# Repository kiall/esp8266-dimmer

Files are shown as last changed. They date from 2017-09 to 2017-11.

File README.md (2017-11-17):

ESP8266 Light Dimmer
====================

KiCad Schematic and PCB Design for a ESP8266 / ESP-03 based light dimmer.

Tested as working - see revision history for more.

## Board Images

Front:

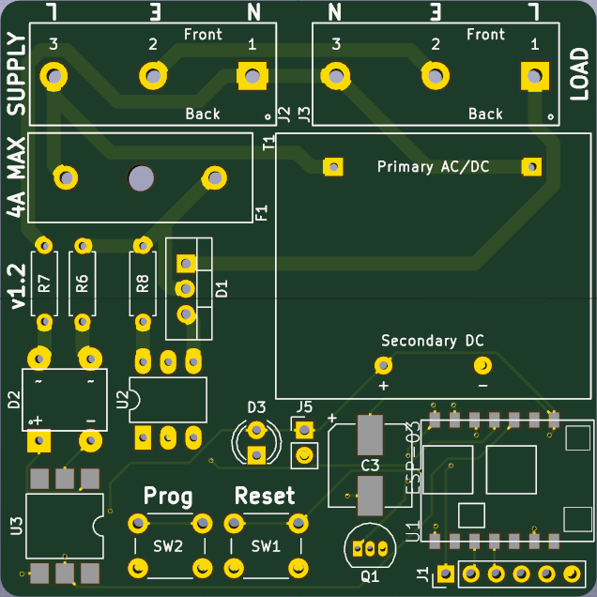
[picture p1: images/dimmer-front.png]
Front


Back:

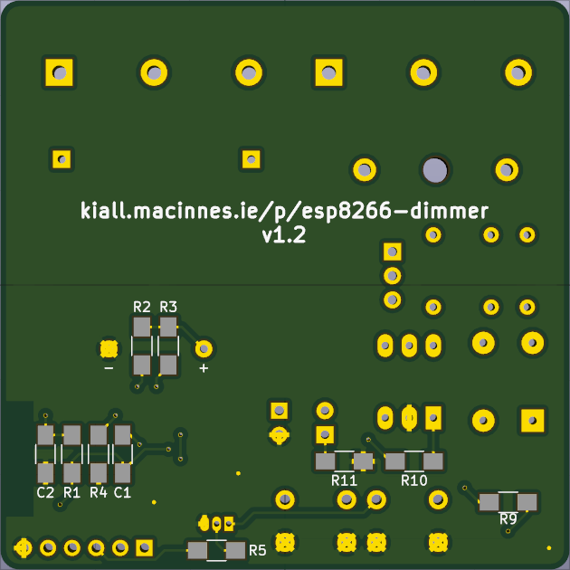
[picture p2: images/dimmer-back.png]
Back


## Revision History:

### v1.2:

v1.2 is tested as working.

Fixes:

* Fix PSU Ordering - Secondary DC + and - pins swapped.
* U3 pad size corrected
* C3 470uF footprint corrected
* Add 3v3 + GND power inputs for programming without a mains connection
* PCB Layout reworked

Issues Not Yet Fixed:

* More space behind D1 (Triac) would be better, to allow for a larger heatsink.
* 3v3 + GND power inputs for programming without a mains connection should be labeled on the board.
### v1.1:

Fixes:

* Fix Traic Pin Ordering

Issues Not Yet Fixed:

* None

## References

* [Dimming Circuit](https://www.instructables.com/id/Arduino-controlled-light-dimmer-The-circuit/)
* [BoM Generator](https://github.com/SchrodingersGat/KiBoM)

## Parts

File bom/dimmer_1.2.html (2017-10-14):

Source File | /home/kiall/kicad/projects/esp8266-dimmer/kicad/dimmer.sch
BoM Date | Sat 14 Oct 2017 14:27:11 IST
Schematic Version | 1.2
Schematic Date
KiCad Version | Eeschema 4.0.7
Component Groups | 23
Component Count (per PCB) | 29
Fitted Components (per PCB) | 29
Number of PCBs | 1
Total Component Count (for 1 PCBs) | 29
 | Description | Part | References | Value | Footprint | Quantity Per PCB | Datasheet
1 | Unpolarized capacitor | C | C1 | 0.1uF | C_1206_HandSoldering | 1
2 | Polarised capacitor | CP | C2 | 0.1uF | C_1206_HandSoldering | 1
3 | Polarised capacitor | CP | C3 | 470uF | CP_Elec_8x10.5 | 1
4 | triode for alternating current (TRIAC) | Q_TRIAC_AAG | D1 | BT136X-600 | TO-220-3_Vertical | 1
5 | Diode bridge (pins: 1=+, 2=-, 3=AC, 4=AC) | DF04M-E3/45 | D2 | DF04M-E3/45 | DF-M | 1
6 | LED generic | LED | D3 | LED | LED_D4.0mm | 1
7 | Fuse, generic | Fuse | F1 | 5A | Fuse_Holder_5x20mm_P15mm | 1
8 | Generic screw terminal, single row, 01x03 | Screw_Terminal_01x03 | J2 | AC IN | RS_Pro_10mm_Pitch_3_Way_PCB_Terminal_Block | 1
9 | Generic connector, single row, 01x06 | Conn_01x06_Female | J1 | FTDI | Socket_Strip_Straight_1x06_Pitch2.54mm | 1
10 | Generic connector, single row, 01x03 | Conn_01x03 | J3 | Load Out | RS_Pro_10mm_Pitch_3_Way_PCB_Terminal_Block | 1
11 | Generic connector, single row, 01x02 | Conn_01x02 | J5 | PWRIN | Pin_Header_Straight_1x02_Pitch2.54mm | 1
12 | Transistor PNP (general) | Q_PNP_EBC | Q1 | S8550 PNP | TO-92_Inline_Narrow_Oval | 1
13 | Resistor | R | R1 R2 R3 R4 R5 R9 | 10k | R_1206_HandSoldering | 6
14 | Resistor | R | R8 | 1k | R_Axial_DIN0207_L6.3mm_D2.5mm_P7.62mm_Horizontal | 1
15 | Resistor | R | R10 | 220 | R_1206_HandSoldering | 1
16 | Resistor | R | R6 R7 | 30k | R_Axial_DIN0207_L6.3mm_D2.5mm_P7.62mm_Horizontal | 2
17 | Resistor | R | R11 | 330 | R_1206_HandSoldering | 1
18 | Single Pole Single Throw (SPST) switch | SW_SPST | SW2 | Prog | SW_PUSH_6mm | 1
19 | Single Pole Single Throw (SPST) switch | SW_SPST | SW1 | Reset | SW_PUSH_6mm | 1
20 | Transformer, single primary, single output, regulated | Transformer_Myrra_47000_1P_1S | T1 | Myrra_47121 | Transformer_Myrra_47000_1P_1S | 1
21 | DC Optocoupler Base Connected, Vce 30V, CTR 20%, Viso 2500V, DIP6 | 4N25 | U3 | 4N25 | SMDIP-6_W9.53mm | 1 | https://www.vishay.com/docs/83725/4n25.pdf
22 | ESP8266 ESP-03 module, 14 pins, 2mm, ceramic antenna | ESP-03 | U1 | ESP-03 | ESP-03 | 1 | http://l0l.org.uk/2014/12/esp8266-modules-hardware-guide-gotta-catch-em-all/
23 | Random Phase Opto-Triac, Vdrm 250V, Ift 15mA, DIP6 | MOC3021M | U2 | MOC3021M | DIP-6_W7.62mm_LongPads | 1 | http://www.fairchildsemi.com/ds/MO/MOC3020M.pdf

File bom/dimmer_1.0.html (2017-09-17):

Source File | /home/kiall/KiCad Projects/dimmer/kicad/dimmer.sch
BoM Date | Sun 17 Sep 2017 14:10:56 IST
Schematic Version | 1.0
Schematic Date
KiCad Version | Eeschema 4.0.7
Component Groups | 22
Component Count (per PCB) | 28
Fitted Components (per PCB) | 28
Number of PCBs | 1
Total Component Count (for 1 PCBs) | 28
 | Description | Part | References | Value | Footprint | Quantity Per PCB | Datasheet
1 | Unpolarized capacitor | C | C1 | 0.1uF | C_1206_HandSoldering | 1
2 | Polarised capacitor | CP | C2 | 0.1uF | C_1206_HandSoldering | 1
3 | Polarised capacitor | CP | C3 | 470uF | C_1206_HandSoldering | 1
4 | triode for alternating current (TRIAC) | Q_TRIAC_AAG | D1 | BT136X-600 | TO-220_Vertical | 1
5 | Diode bridge (pins: 1=+, 2=-, 3=AC, 4=AC) | DF04M-E3/45 | D2 | DF04M-E3/45 | DF-M | 1
6 | LED generic | LED | D3 | LED | LED_D4.0mm | 1
7 | Fuse, generic | Fuse | F1 | 5A | Fuse_Holder_5x20mm_P15mm | 1
8 | Generic screw terminal, single row, 01x03 | Screw_Terminal_01x03 | J2 | AC IN | RS_Pro_10mm_Pitch_3_Way_PCB_Terminal_Block | 1
9 | Generic connector, single row, 01x06 | Conn_01x06_Female | J1 | FTDI | Socket_Strip_Straight_1x06_Pitch2.54mm | 1
10 | 2-pin jumper/solder bridge | GS2 | J4 | LED_BYPASS | GS2 | 1
11 | Generic connector, single row, 01x03 | Conn_01x03 | J3 | Load Out | RS_Pro_10mm_Pitch_3_Way_PCB_Terminal_Block | 1
12 | Transistor PNP (general) | Q_PNP_EBC | Q1 | S8550 PNP | TO-92_Inline_Narrow_Oval | 1
13 | Resistor | R | R1 R2 R3 R4 R5 R9 | 10k | R_1206_HandSoldering | 6
14 | Resistor | R | R8 | 1k | R_Axial_DIN0207_L6.3mm_D2.5mm_P7.62mm_Horizontal | 1
15 | Resistor | R | R10 | 220 | R_1206_HandSoldering | 1
16 | Resistor | R | R6 R7 | 30k | R_Axial_DIN0207_L6.3mm_D2.5mm_P7.62mm_Horizontal | 2
17 | Single Pole Single Throw (SPST) switch | SW_SPST | SW2 | Prog | SW_PUSH_6mm | 1
18 | Single Pole Single Throw (SPST) switch | SW_SPST | SW1 | Reset | SW_PUSH_6mm | 1
19 | Transformer, single primary, single output, regulated | Transformer_Myrra_47000_1P_1S | T1 | Myrra_47121 | Transformer_Myrra_47000_1P_1S | 1
20 | DC Optocoupler Base Connected, Vce 30V, CTR 20%, Viso 2500V, DIP6 | 4N25 | U3 | 4N25 | DIP-6_W7.62mm_SMD | 1 | https://www.vishay.com/docs/83725/4n25.pdf
21 | ESP8266 ESP-03 module, 14 pins, 2mm, ceramic antenna | ESP-03 | U1 | ESP-03 | ESP-03 | 1 | http://l0l.org.uk/2014/12/esp8266-modules-hardware-guide-gotta-catch-em-all/
22 | Random Phase Opto-Triac, Vdrm 250V, Ift 15mA, DIP6 | MOC3021M | U2 | MOC3021M | DIP-6_W7.62mm_LongPads | 1 | http://www.fairchildsemi.com/ds/MO/MOC3020M.pdf

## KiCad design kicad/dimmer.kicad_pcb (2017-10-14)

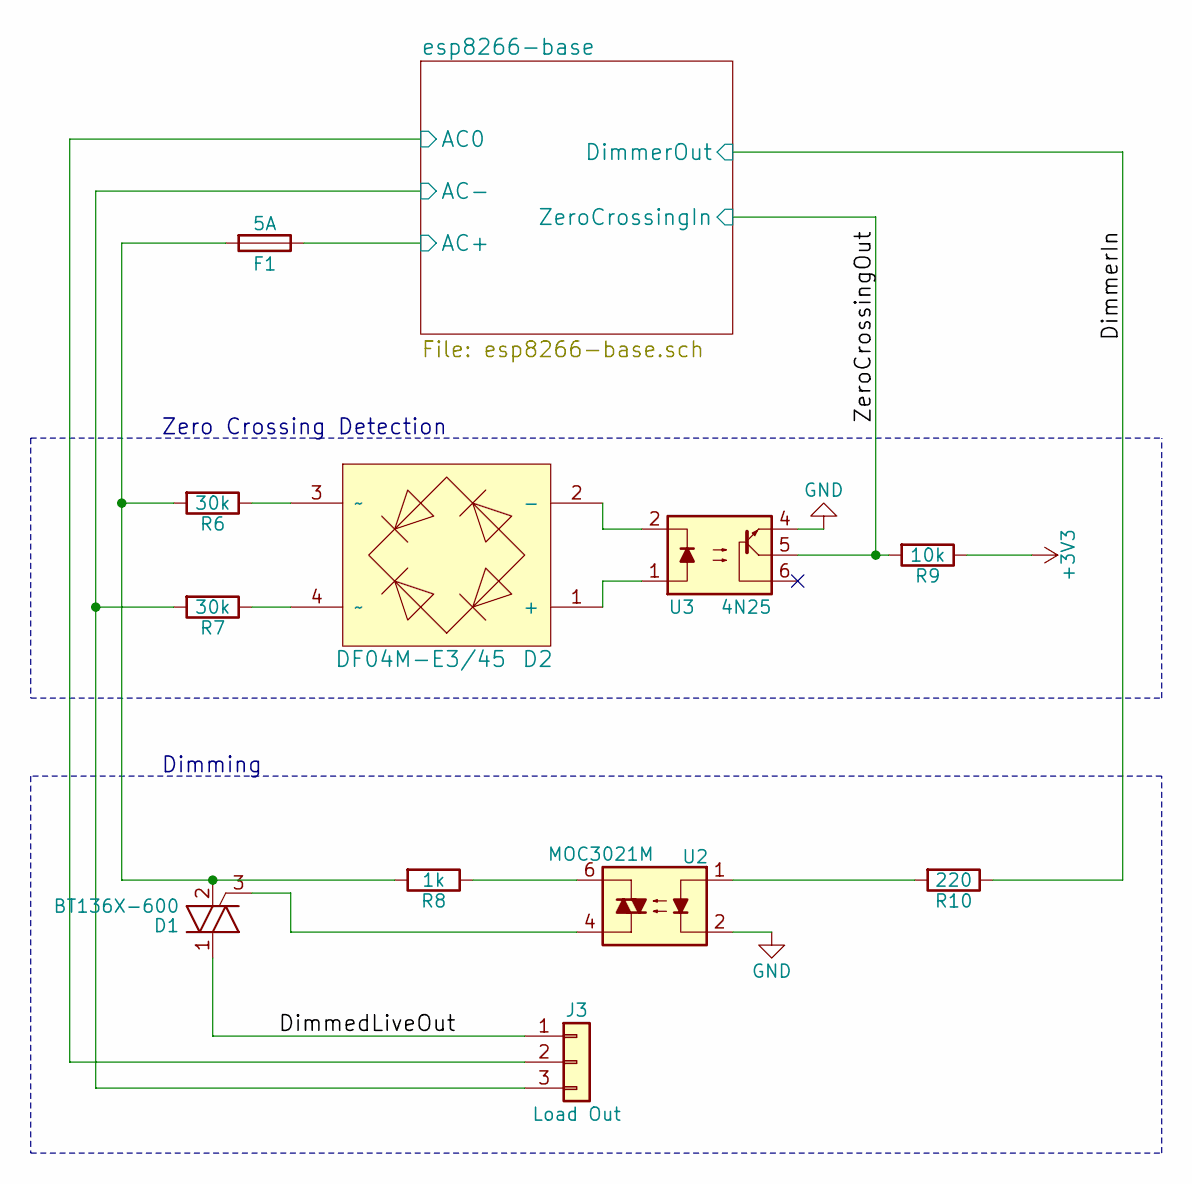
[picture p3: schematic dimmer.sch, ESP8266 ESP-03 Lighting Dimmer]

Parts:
D1: BT136X-600; TO-220-3_Vertical
D2: DF04M-E3/45; DF-M
F1: 5A; Fuse_Holder_5x20mm_P15mm
J3: Load Out; RS_Pro_10mm_Pitch_3_Way_PCB_Terminal_Block
R6, R7: 30k; R_Axial_DIN0207_L6.3mm_D2.5mm_P7.62mm_Horizontal
R8: 1k; R_Axial_DIN0207_L6.3mm_D2.5mm_P7.62mm_Horizontal
R9: 10k; R_1206_HandSoldering
R10: 220; R_1206_HandSoldering
U2: MOC3021M; DIP-6_W7.62mm_LongPads
U3: 4N25; SMDIP-6_W9.53mm

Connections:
+3V3: R9.1; also elsewhere on the board
/DimmedLiveOut: D1.1 (A1), J3.1
/DimmerIn: R10.1; also elsewhere on the board
/ZeroCrossingOut: R9.2, U3.5; also elsewhere on the board
/esp8266-base/AC0: J3.2; also elsewhere on the board
/esp8266-base/AC+: F1.1; also elsewhere on the board
/esp8266-base/AC-: J3.3, R7.2; also elsewhere on the board
GND: U2.2, U3.4; also elsewhere on the board
unnamed: D1.2 (A2), F1.2, R6.2, R8.2
unnamed: D1.3 (G), U2.4
unnamed: D2.1 (+), U3.1
unnamed: D2.2 (-), U3.2
unnamed: D2.3 (~~), R6.1
unnamed: D2.4 (~~), R7.1
unnamed: R8.1, U2.6
unnamed: R10.2, U2.1

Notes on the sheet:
Zero Crossing Detection
Dimming

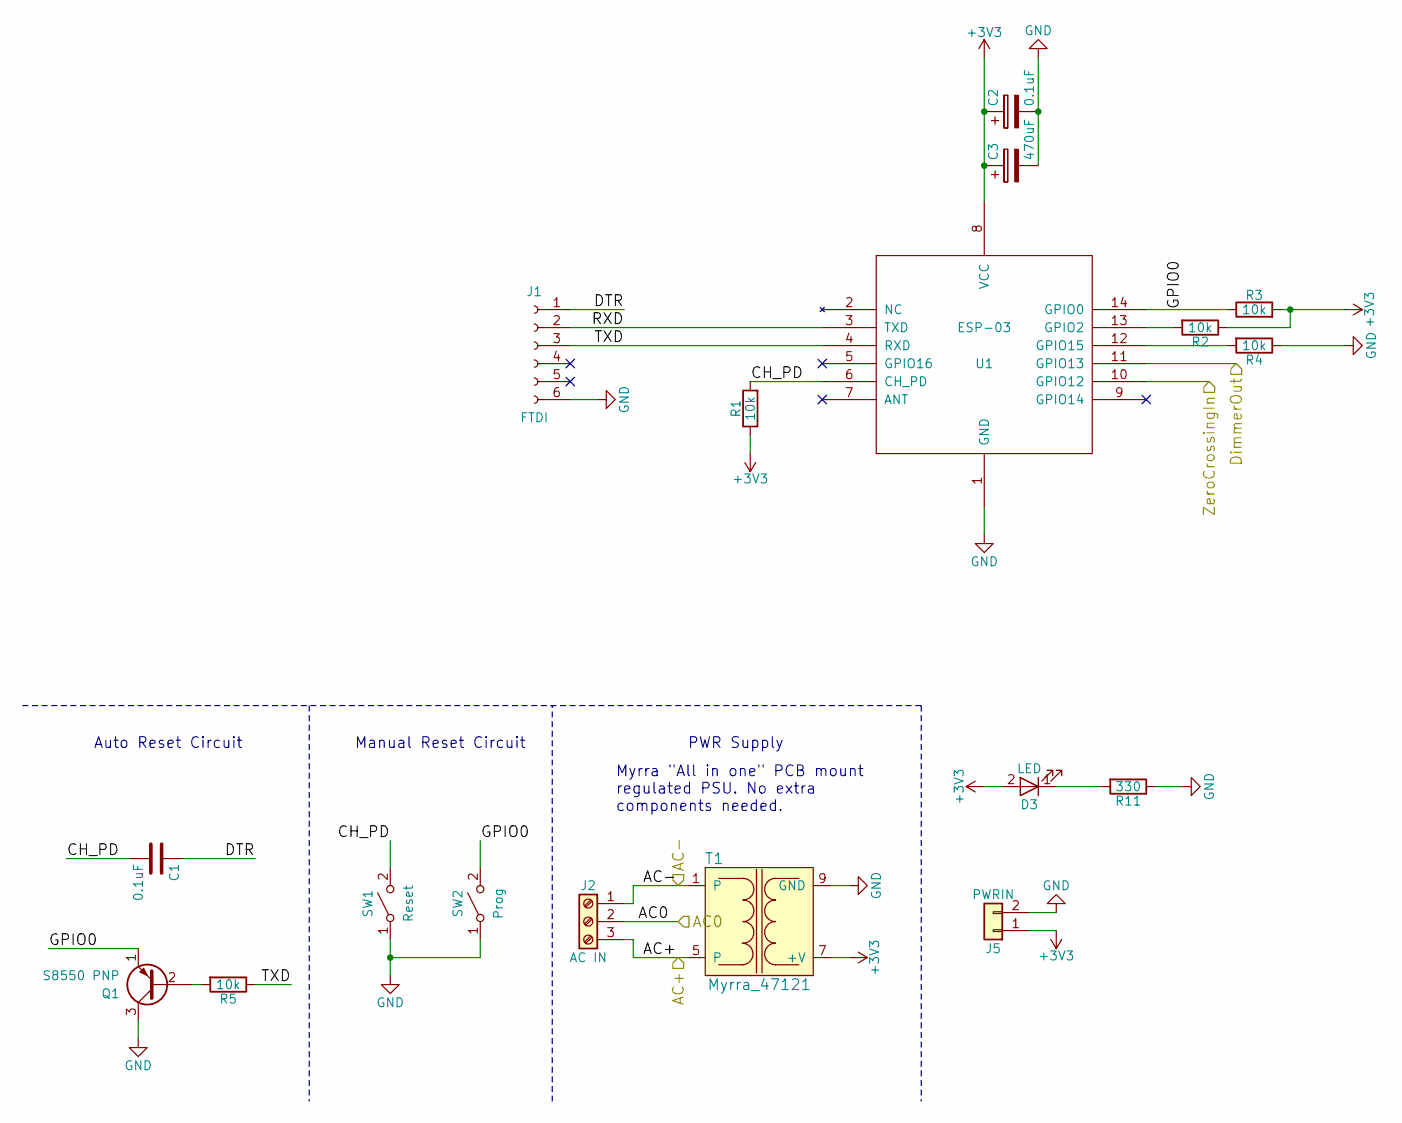
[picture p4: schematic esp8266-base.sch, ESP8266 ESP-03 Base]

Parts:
C1, C2: 0.1uF; C_1206_HandSoldering
C3: 470uF; CP_Elec_8x10.5
D3: LED; LED_D4.0mm
J1: FTDI; Socket_Strip_Straight_1x06_Pitch2.54mm
J2: AC IN; RS_Pro_10mm_Pitch_3_Way_PCB_Terminal_Block
J5: PWRIN; Pin_Header_Straight_1x02_Pitch2.54mm
Q1: S8550 PNP; TO-92_Inline_Narrow_Oval
R1, R2, R3, R4, R5: 10k; R_1206_HandSoldering
R11: 330; R_1206_HandSoldering
SW1: Reset; SW_PUSH_6mm
SW2: Prog; SW_PUSH_6mm
T1: Myrra_47121; Transformer_Myrra_47000_1P_1S
U1: ESP-03

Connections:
+3V3: C2.1, C3.1, D3.2 (A), J5.1, R1.1, R2.1, R3.2, T1.7 (+V), U1.8 (VCC); also elsewhere on the board
/DimmerIn: U1.11 (GPIO13); also elsewhere on the board
/ZeroCrossingOut: U1.10 (GPIO12); also elsewhere on the board
/esp8266-base/AC0: J2.2; also elsewhere on the board
/esp8266-base/AC+: J2.3, T1.5; also elsewhere on the board
/esp8266-base/AC-: J2.1, T1.1; also elsewhere on the board
/esp8266-base/CH_PD: C1.2, R1.2, SW1.2 (B), U1.6 (CH_PD)
/esp8266-base/DTR: C1.1, J1.1
/esp8266-base/GPIO0: Q1.1 (E), R3.1, SW2.2 (B), U1.14 (GPIO0)
/esp8266-base/RXD: J1.2, U1.3 (TXD)
/esp8266-base/TXD: J1.3, R5.1, U1.4 (RXD)
GND: C2.2, C3.2, J1.6, J5.2, Q1.3 (C), R4.1, R11.1, SW1.1 (A), SW2.1 (A), T1.9 (GND), U1.1 (GND); also elsewhere on the board
unnamed: D3.1 (K), R11.2
unnamed: Q1.2 (B), R5.2
unnamed: R2.2, U1.13 (GPIO2)
unnamed: R4.2, U1.12 (GPIO15)

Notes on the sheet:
Auto Reset Circuit
Manual Reset Circuit
PWR Supply
Myrra "All in one" PCB mount regulated PSU. No extra components needed.

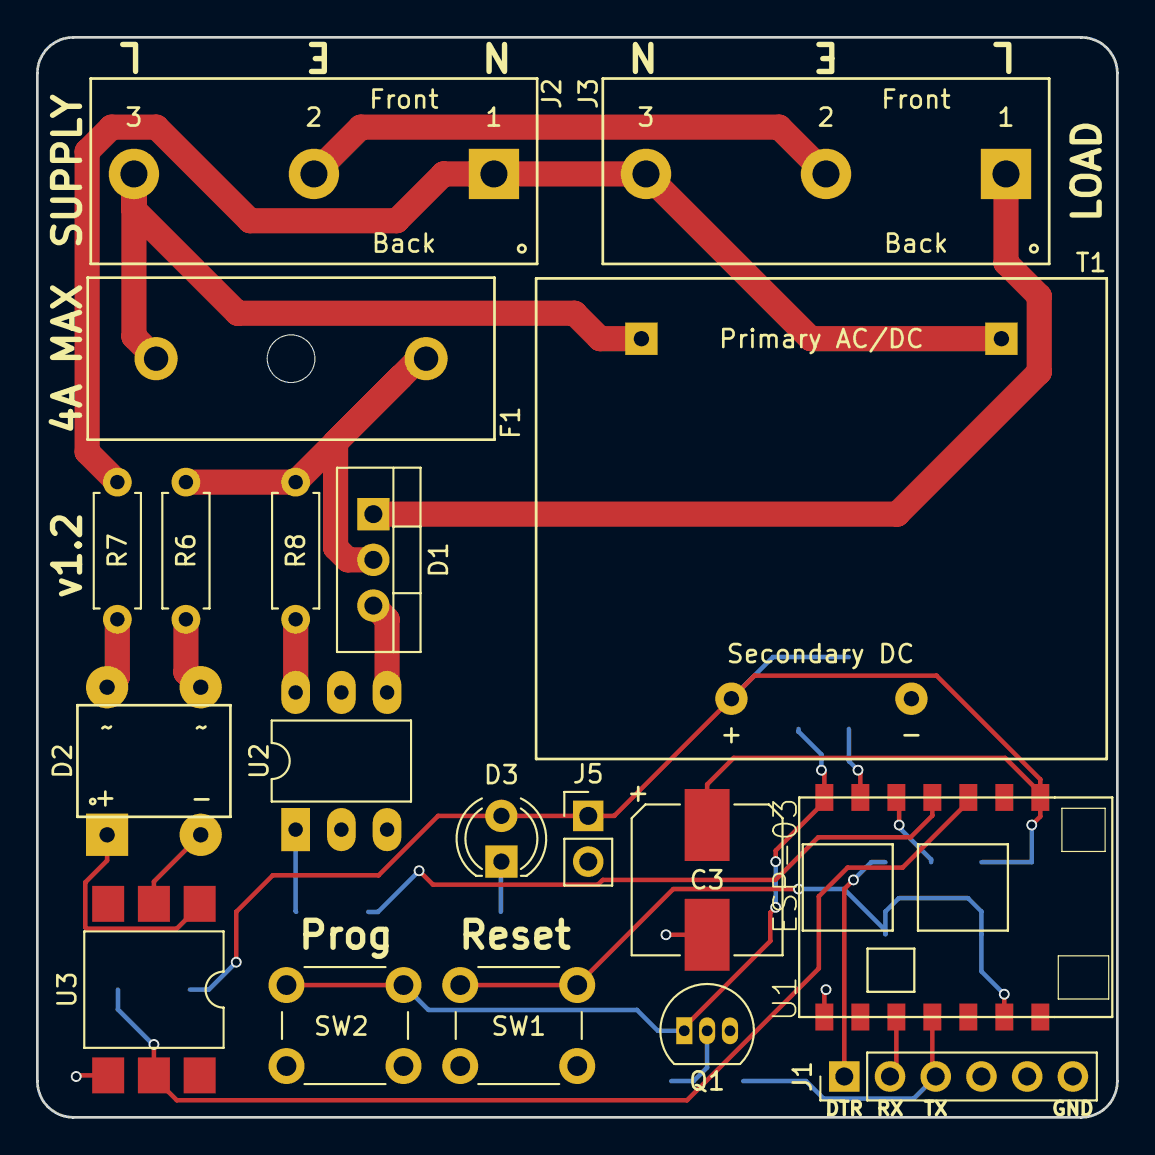
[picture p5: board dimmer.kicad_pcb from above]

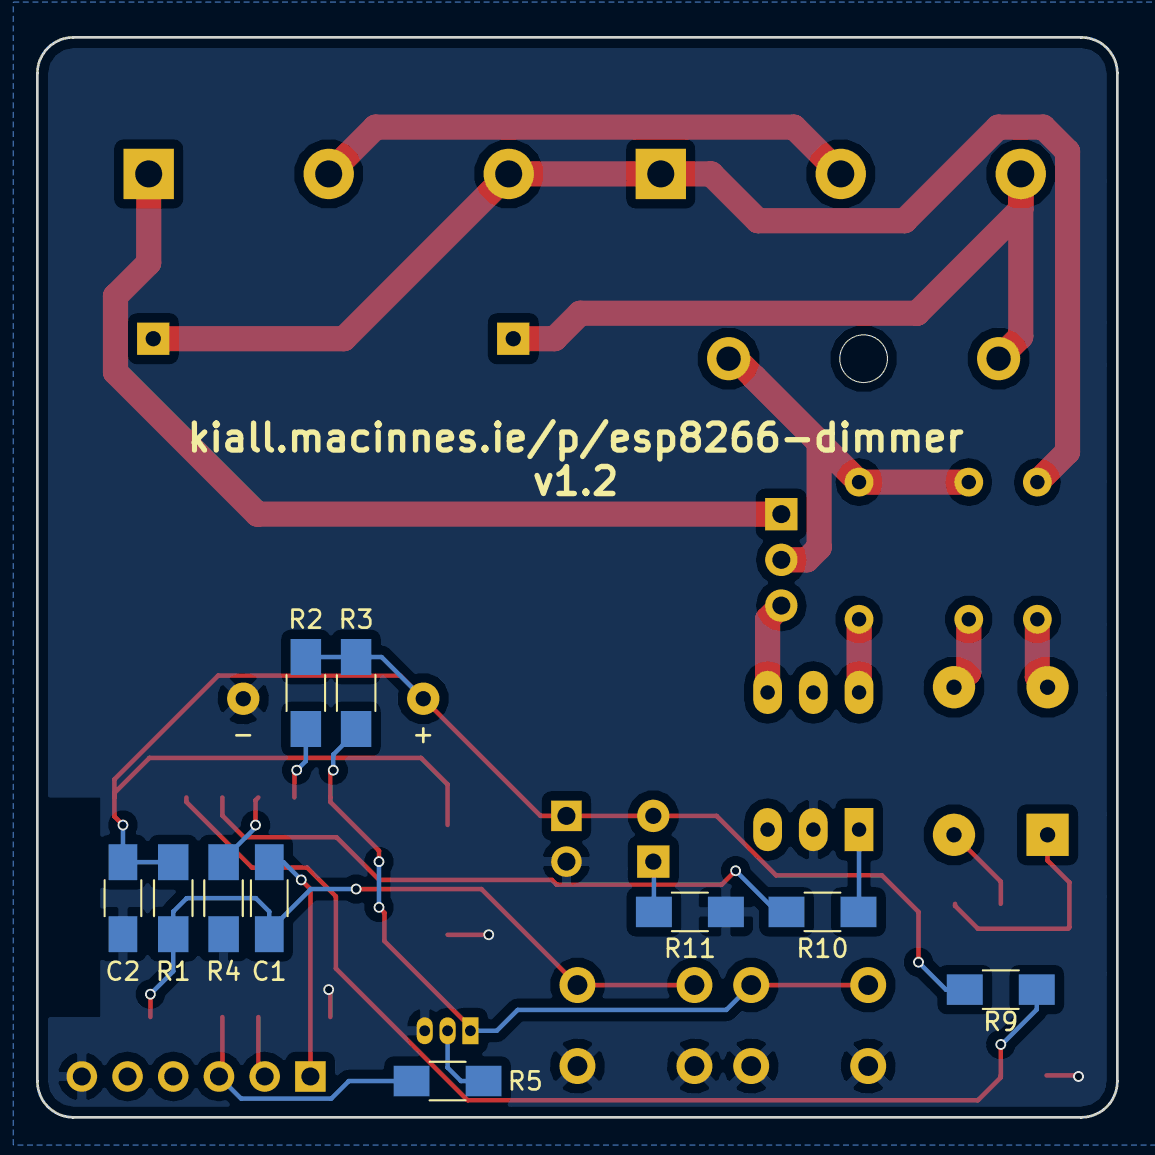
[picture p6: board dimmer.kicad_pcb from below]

Board: 2 copper layers, 60.0 x 60.0 mm, 29 parts (10 on the bottom side), 25 nets.

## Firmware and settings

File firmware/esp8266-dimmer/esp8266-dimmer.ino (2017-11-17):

#include <ESP8266MQTTClient.h>
#include <ESP8266WiFi.h>
#include <ESP8266mDNS.h>
#include <ArduinoOTA.h>

MQTTClient mqtt;

const char* HOSTNAME = ("esp8266-dimmer-" + String(ESP.getChipId())).c_str();
const char* WIFI_SSID = "<Wifi Name Here>";
const char* WIFI_PASSWORD = "<Wifi Password Here>";
const char* OTA_PASSWORD = "<OTA Password Here>";
const String MQTT_URI = "mqtt://<MQTT Server Here>:1883";

const int AC_PIN = 13;                           // Output To Dimming Circuit
const int ZC_PIN = 12;                           // Input from Zero Cross Detection Circuit
const int STATE_TIMER_INTERVAL = 80000000L;      // Timer interval in clock cycles. 80Mhz, so 80000000L cycles a second.
const int DIMMER_TIMER_INTERVAL = 6000;          // Timer interval in clock cycles. 80Mhz, so 80000000L cycles a second.

const String COMMAND_TOPIC = "esp8266-dimmer/" + String(ESP.getChipId()) + "/command";
const String STATE_TOPIC = "esp8266-dimmer/" + String(ESP.getChipId()) + "/state";
const String BRIGHTNESS_COMMAND_TOPIC = "esp8266-dimmer/" + String(ESP.getChipId()) + "/brightness/command";
const String BRIGHTNESS_STATE_TOPIC = "esp8266-dimmer/" + String(ESP.getChipId()) + "/brightness/state";

bool POWER_ON = false;
int BRIGHTNESS = 128;   // Dimming level (0-128)  0 = ON, 128 = OFF

volatile boolean ZC_DETECTED = false;
volatile int ZC_COUNTER = 0;
volatile boolean STATE_UPDATE_DUE = true;

void setup() {
  Serial.begin(74880);
  Serial.println("Booting");

  setupWifi();
  setupOta();
  setupGpio();
  setupMqtt();
  setupTimers();

  Serial.println("Booted");
}

void setupWifi() {
  WiFi.begin(WIFI_SSID, WIFI_PASSWORD);
  Serial.print("Wifi Connecting");

  while (WiFi.status() != WL_CONNECTED) {
    delay(500);
    Serial.print(".");
  }

  Serial.print("\n");
  Serial.print("IP address: ");
  Serial.println(WiFi.localIP());
}

void setupOta() {
  ArduinoOTA.setHostname(HOSTNAME);
  ArduinoOTA.setPassword(OTA_PASSWORD);

  ArduinoOTA.onStart([]() {
    disableTimers();
    noInterrupts();

    sendStatusUpdate();
    Serial.println("OTA Start");
  });

  ArduinoOTA.onEnd([]() {
    Serial.println("\nOTA End");
  });

  ArduinoOTA.onProgress([](unsigned int progress, unsigned int total) {
    Serial.printf("OTA Progress: %u%%\r\n", (progress / (total / 100)));
  });

  ArduinoOTA.onError([](ota_error_t error) {
    Serial.printf("OTA Error[%u]: ", error);
    if (error == OTA_AUTH_ERROR) Serial.println("OTA Auth Failed");
    else if (error == OTA_BEGIN_ERROR) Serial.println("OTA Begin Failed");
    else if (error == OTA_CONNECT_ERROR) Serial.println("OTA Connect Failed");
    else if (error == OTA_RECEIVE_ERROR) Serial.println("OTA Receive Failed");
    else if (error == OTA_END_ERROR) Serial.println("OTA End Failed");
  });

  Serial.println("OTA Setup");
  ArduinoOTA.begin();
}

void setupGpio() {
  pinMode(AC_PIN, OUTPUT);
  attachInterrupt(digitalPinToInterrupt(ZC_PIN), onZeroCrossing, RISING);
}

void setupMqtt() {
  mqtt.onData([](String topic, String data, bool cont) {
    Serial.printf("Data received, topic: %s, data: %s\r\n", topic.c_str(), data.c_str());
    if (topic == COMMAND_TOPIC) {
      onCommand(data);
    } else if (topic == BRIGHTNESS_COMMAND_TOPIC) {
      onBrightnessCommand(data);
    } else {
      Serial.println("Unknown topic: " + topic);
    }
  });

  mqtt.onSubscribe([](int sub_id) {
    Serial.printf("Subscribe topic id: %d ok\r\n", sub_id);
  });

  mqtt.onConnect([]() {
    Serial.printf("MQTT: Connected\r\n");

    mqtt.subscribe(COMMAND_TOPIC);
    mqtt.subscribe(BRIGHTNESS_COMMAND_TOPIC);
  });

  Serial.println("MQTT Connecting");
  mqtt.begin(MQTT_URI);
}

void setupTimers() {
  noInterrupts();

  timer0_isr_init();
  timer0_attachInterrupt(onDimmerTimer);

  resetDimmerTimer();

  timer1_isr_init();
  timer1_enable(TIM_DIV16, TIM_EDGE, TIM_SINGLE);
  timer1_attachInterrupt(onStateTimer);

  resetStateTimer();

  interrupts();
}

void disableTimers() {
  noInterrupts();
  timer0_detachInterrupt();
  timer1_disable();
  timer1_detachInterrupt();
  interrupts();
}

void resetDimmerTimer() {
  timer0_write(ESP.getCycleCount() + DIMMER_TIMER_INTERVAL);
}

void resetStateTimer() {
  timer1_write(STATE_TIMER_INTERVAL);
}

void loop()  {
  mqtt.handle();
  ArduinoOTA.handle();

  if (STATE_UPDATE_DUE == true) {
    sendStatusUpdate();
  }
}

void setPowerState(boolean state) {
  if (state == true) {
    setBrightness(0);
  } else {
    setBrightness(128);
  }
}

void setBrightness(int brightness) {
  Serial.println("Setting Brightness to: " + String(BRIGHTNESS));

  BRIGHTNESS = brightness;

  if (brightness == 128) {
    POWER_ON = false;
  } else {
    POWER_ON = true;
  }

  STATE_UPDATE_DUE = true;
}

void onCommand(String data) {
  if (data == "ON") {
    Serial.println("Setting Power ON");
    setPowerState(true);
  } else if (data == "OFF") {
    Serial.println("Setting Power OFF");
    setPowerState(false);
  } else {
    Serial.println("Unknown command payload: " + data);
  }

  STATE_UPDATE_DUE = true;
}

void onBrightnessCommand(String data) {
  // TODO: Bad Data Handling
//  Serial.println("Setting Brightness to: " + data);

  int inverseBrighness = data.toInt();
  setBrightness((inverseBrighness * -1) + 128);
}

void onZeroCrossing() {
  if (POWER_ON == true) {
      ZC_DETECTED = true;
      ZC_COUNTER=0;
  }

  digitalWrite(AC_PIN, LOW);
}

void onDimmerTimer() {
//  Serial.println("Dimmer Timer");
  if (ZC_DETECTED == true) {
    if (ZC_COUNTER >= BRIGHTNESS) {
      digitalWrite(AC_PIN, HIGH);
      ZC_COUNTER = 0;
      ZC_DETECTED = false;
    } else {
      ZC_COUNTER++;
    }
  }

  resetDimmerTimer();
}

void onStateTimer() {
  STATE_UPDATE_DUE = true;
  resetStateTimer();
}

void sendStatusUpdate() {
  STATE_UPDATE_DUE = false;

  if (POWER_ON == true) {
    mqtt.publish(STATE_TOPIC, "ON");
  } else {
    mqtt.publish(STATE_TOPIC, "OFF");
  }
  //  Serial.println("Brightness: " + String((BRIGHTNESS * -1) + 128));
  mqtt.publish(BRIGHTNESS_STATE_TOPIC, String((BRIGHTNESS * -1) + 128));
}

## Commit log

2017-09-17 Add Bill of Materials
2017-09-17 Add Gerber files
    [dimmer-B.Cu.gbl, dimmer-B.Mask.gbs, dimmer-B.Paste.gbp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]
2017-09-17 Add BoM in text format
2017-09-17 Add some more descriptive text
    [dimmer.kicad_pcb, dimmer.sch]
2017-09-17 Add HK
    Someone I know has a "problem" with HK ;)
    [dimmer.kicad_pcb]
2017-09-17 Rev 1.1: Fix triac connections
    Pins 1 and 2 on the triac D1 were connected in backwords, preventing
    the circuit from working.
    [dimmer-B.Cu.gbl, dimmer-B.Mask.gbs, dimmer-B.Paste.gbp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]
2017-10-14 Update for v1.2 - Fixes and board redesign
    [dimmer-B.Cu.gbl, dimmer-B.Mask.gbs, dimmer-B.Paste.gbp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]
2017-10-15 Update 1.2 gerbers
    [dimmer-B.Cu.gbl, dimmer-B.Mask.gbs, dimmer-B.Paste.gbp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]
